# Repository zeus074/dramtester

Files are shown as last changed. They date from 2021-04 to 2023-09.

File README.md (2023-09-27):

# Dramtester V 4.2.1 by Mirco Gaggiottini
Dram tester for 4116 and 4164/256 (now in beta testing for serial communication)

Simple project taken from the base of @FozzTexx

with added support for 4116 memories and a status display.

This Tester supports 4164,41256,4116,*4532* and pin compatible Dram.

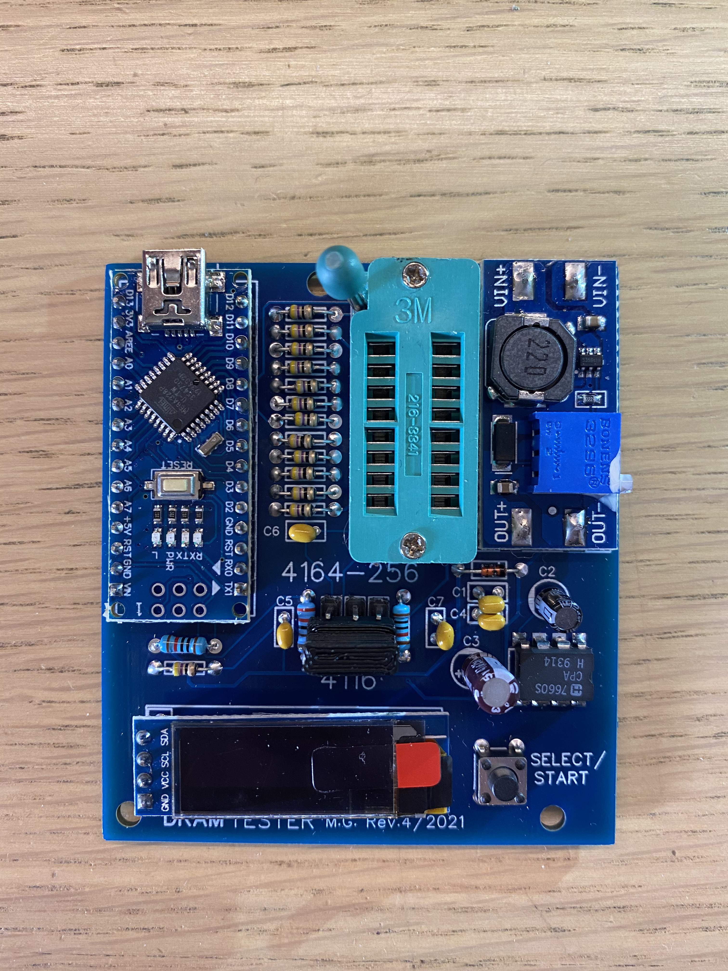
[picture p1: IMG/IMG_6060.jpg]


:coffee: if you want the PCB, please support me and follow this link : <a href="https://www.pcbway.com/project/shareproject/Dram_tester_for_4116_4164_256_and_4532_d6b7143c.html" target="_NEW">PCBWAY!</a>

**Components:**

C1,C4,C5,C6,C7: 100nF

C2: 10uF 25v

C3: 47uf 25v

D1: BAT43 (optional, you can short)

DC: MT3608 (DC-DC converter - 4~5V in, 12V out)

Disp: Display oled 128x32 i2c

H1,H2,H3: 3 pin Header-Male 2.54

R1-R13: 47 Ω 1/8w (optional)

R14,R16: 10k Ω 1/4w

R15: 2.2k Ω 1/4w

1x Arduino Nano

1x Zif 16 pin (or 16 pin socket)

1x 7760 (7660s)

1x tactile switch 6x6

N.B.: The DC-DC must be able to accept 4V on input and must be set to output 12V

**Directory**

Gerber : https://www.pcbway.com/project/shareproject/Dram_tester_for_4116_4164_256_and_4532_d6b7143c.html

IMG : Tester's pictures

Firmware : Firmware for Arduino Nano (you can use avr commands like Arduino's IDE or an AVR programmer to write the HEX file)

Source : Source file to compile for Arduino

Beta folder (inside firmware/source) : software/firmware with serial communication, without LCD (9600 baud)

**How it works**

First you need to flash the firmware on arduino of course!.

Before inserting the ram select the correct setting with the jumpers: (all jumpers must be in the same position, all high for 4164 or all low for 4116)



If the setting is on 4164-256 it is possible to select the type of memory (from 4164,41256,4532-L,4532-H) by briefly pressing the select / start key.
(memory 4116 has no selections)

To start the test, keep the select / start key pressed for 1 sec.

After the test the result will be displayed, if there is an error the test will stop and the point of the error will be shown.

**How to burn the firmware**

You can use avrdude integrated on arduini via command line, or simply download a gui (if you use windows) like AVRDUDESS.
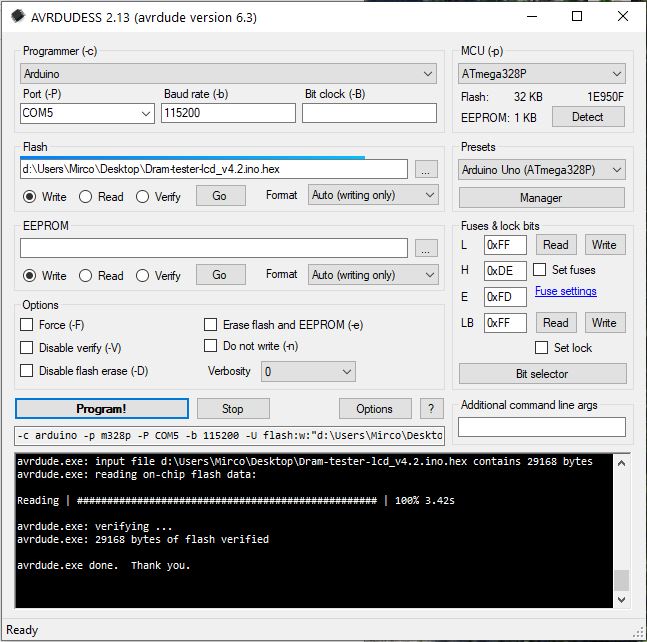
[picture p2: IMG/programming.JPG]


**Support 3D Print**

Thanks to seanch80, you can print the base in 3D, the stl file is in the 3D_print folder.
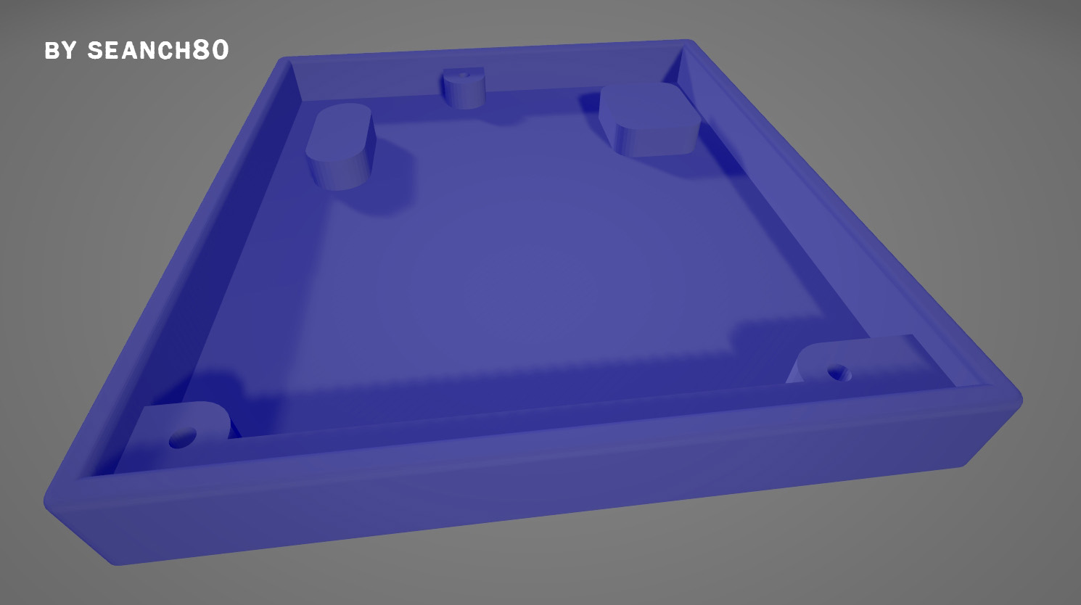
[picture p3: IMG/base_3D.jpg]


You will also find a "3jumpers" file to be able to glue the 3 jumpers in order to easily move them all together.
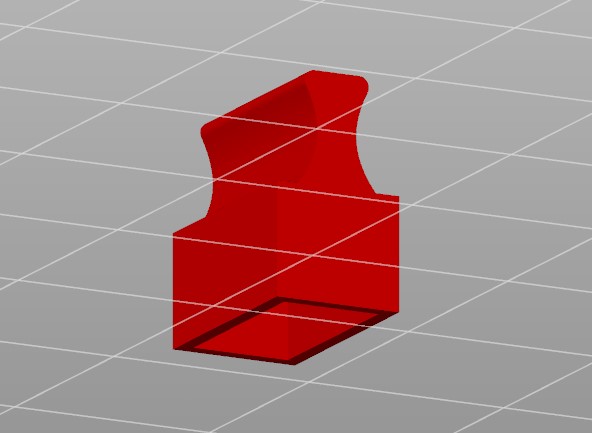
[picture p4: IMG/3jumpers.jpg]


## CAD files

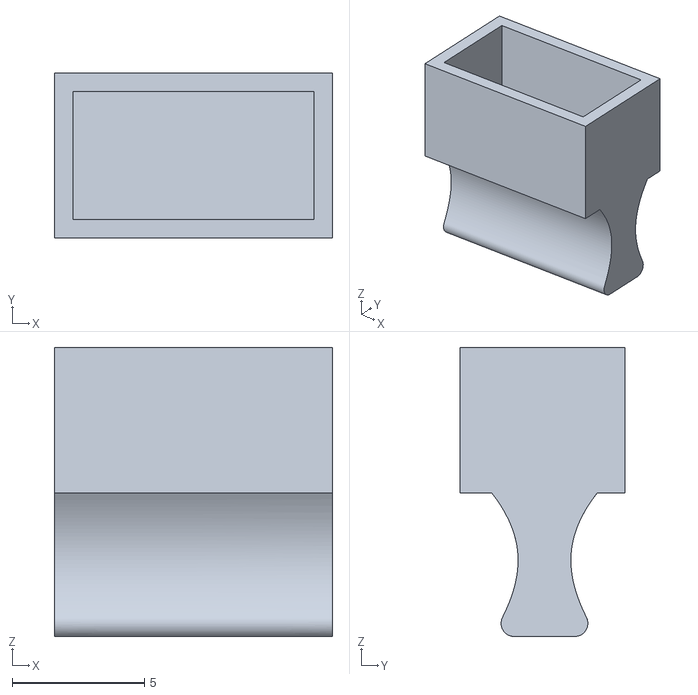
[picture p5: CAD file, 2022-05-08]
3D_Print/3jumpers.stl
10.5 x 6.25 x 10.9

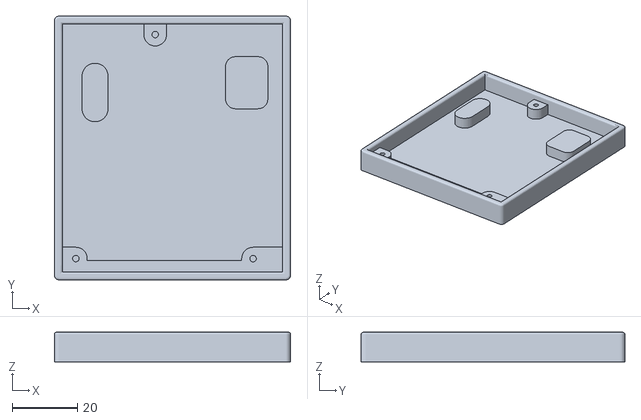
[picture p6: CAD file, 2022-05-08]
3D_Print/DRAMTesterBase_01.stl
72.6 x 81.1 x 9.10

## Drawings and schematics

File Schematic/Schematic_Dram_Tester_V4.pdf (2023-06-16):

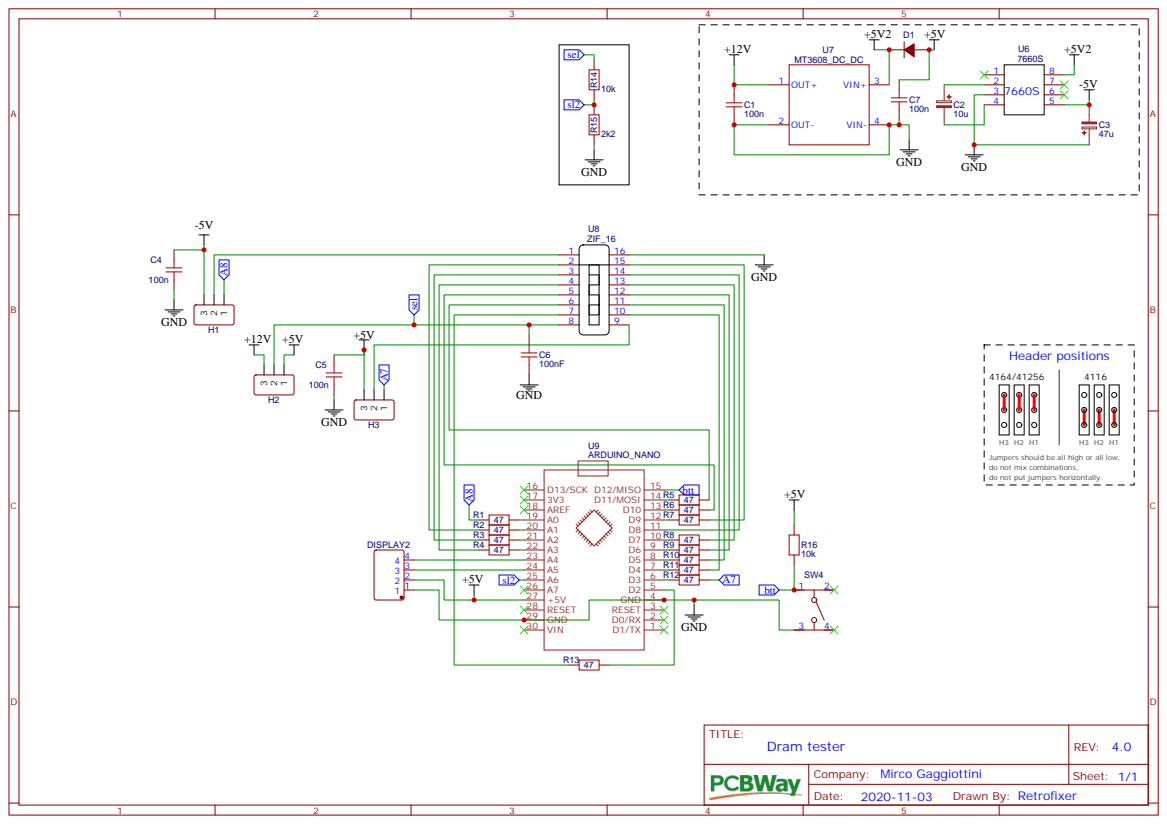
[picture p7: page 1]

Jumpers should be all high or all low,
do not mix combinations,
do not put jumpers horizontally.

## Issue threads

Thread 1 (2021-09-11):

.INO file for Arduino IDE

repetto74, 2021-09-11:
Hi,
I am building this very nice project.
I used to program my Arduino boards with the Arduino IDE but it requires files with .ino extension (while yours is a compiled hex).
Any chance to add also the .ino file to load on the Arduino IDE?
Many thanks.
Rick

zeus074, 2021-09-13:
Hi, yes the .ino file is the source code and is still under development, so I had put the hex and update it from time to time. if you want you can also load the hex with the Arduino compiler, you have to go from the command line to the folder where the software is installed and launch avrdude.
ES:
C: \ Users \ "Your username" \ AppData \ Local \ Arduino15 \ packages \ arduino \ tools \ avrdude \ 6.3.0-arduino17 / bin / avrdude -CC: \ Users \ "your username" \ AppData \ Local \ Arduino15 \ packages \ arduino \ tools \ avrdude \ 6.3.0-arduino17 / etc / avrdude.conf -v -patmega328p -carduino -PCOM5 -b115200 -D -Uflash: w: C: \ Path hex file "win-temp \ arduino_build_678219 / Dram -lcd_v4.2.ino.hex-tester: i

Alternatively you can simply download an ide for avrdude and launch the firmware from there:
https://blog.zakkemble.net/avrdudess-a-gui-for-avrdude/

repetto74, 2021-09-13:
Hi Mirco,

Thank you for your time :-)
I finally tried AVRDUDESS on a Windows machine (I am on MacOSX) and I could
load the hex pretty easily on the Nano :-)
Still waiting for the PCB to build this nice project.
I assume that the DC DC booster converter needs to be set to +12v (with the
variable resistor) as those will be used by the 4116s ?
Best regards,
Riccardo

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

--
Riccardo Repetto
@ AppleWorld...

zeus074, 2021-09-13:
Yes the dc-dc converter must be set to 12v. for dram 4116s i have never tried them but i think it works.
Regards.

Mirco.

repetto74, 2021-09-30:
Ciao Mirco :-)

Ho capito che sei italiano, hai un canale Youtube.
Ho montato il tuo tester DRAM e funziona benissimo con le 4164 :-).
Riscontro pero' un problema per le 4116. Ho cercato di regolare il booster
a +12v in uscita ma niente quando giro il potenziometro il voltaggio non si
muove sul multimetro e rimane a 3.9v in uscita. In entrata ho 4v precisi il
che sembra bassino mentre sull'Arduino mini misuro 4.6v.
Non capisco dove stia sbagliando nel cercare di regolare il booster.
Possibile che sia fallato? Ne ho altri di ricambio ma forse prima dovrei
controllare altro?

PS : I jumper sono stati posizionati correttamente sulle 4116.

Grazie in anticipo per il tuo eventuale consiglio :-)
Riccardo

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

--
Riccardo Repetto
@ AppleWorld...

zeus074, 2021-09-30:
Ciao Ricardo, il booster sarebbe meglio se regolato prima di metterlo nel circuito così sei sicuro del suo funzionamento, ma non è sicuramente questo il problema. La 12V è usata solo nell selettore - pin del 4116, quindi da escludere un abbassamentp da assorbimento anomalo.
Controlla che il booster accetti una tensione di 4-5v in ingresso, alcuni funzionano solo con tensioni più elevate.
Controlla anche i pin di ingresso che magari non fosse stato collegato al contrario se non ci sono serigrafie ad indicare in - out.
Se tutto questo è corretto allora non funziona il dc-dc.
il dc-dc che ho usato io è questo:
https://www.amazon.it/dp/B07MY3NZ18/ref=cm_sw_em_r_mt_dp_EECSXGNEZ534HXSNFZWJ?_encoding=UTF8&psc=1

repetto74, 2021-10-01:
Ciao Mirco,

Ho preso questo booster per 4 lire su Aliexpress pensando fosse una sola
:-). Ma vedi a non sapere bene come usarlo si pensa male.
Devo dare parecchi giri al trimmer per iniziare a vedere un cambiamento dei
valori delle tensioni. Dopo 10 giri mi fermavo pensando che non funzionasse
invece bisogna dare almeno 20 giri e più per regolarlo :-). Adesso funziona
con +12v precisi in uscita sul multimetro :-).
Ottimi progetto mi mancava questo tester RAM quando aggiusto le PCB dei C64
e macchine Spectrum :-)
Grazie a te!
Riccardo

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

--
Riccardo Repetto
@ AppleWorld...

Closed 2021-09-13.

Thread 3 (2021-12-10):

What is the use of the DC-DC converter and what is the expected input-output voltage values?

jsanpe, 2021-12-10:
I came across this tester while looking for a way to test my 4164 ram chips. Looks really neat. However the documentation does not specify how the dc-dc converter is used, and especifically the input-output voltages it expects.

Thanks in advance for your help

zeus074, 2021-12-10:
Hi, the dc-dc just accept 5v input and the output must be adjusted to 12v.
One like this:  https://www.amazon.it/dp/B079H3YD8V/ref=cm_sw_em_r_mt_dp_5123NFZSSCG85CHP4JRM?_encoding=UTF8&psc=1
They are called MT3608

jsanpe, 2021-12-10:
Thanks, maybe worth updating the readme.md to specify the 12v expected output.
Cheers

Closed 2021-12-10.

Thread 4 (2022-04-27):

PCBWay gerbers

electron99, 2022-04-27:
Hello,

Is this PCBWay account yours?

https://www.pcbway.com/project/shareproject/Dram_Tester_OLED_7f572d5b.html

zeus074, 2022-04-27:
Hi, no it's not my account.
Someone have printed it and inserted on Pcbway, I found it also on Ebay

Closed 2022-05-08.

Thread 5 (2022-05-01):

Roughly -4V instead of -5V

seanch80, 2022-05-01:
Hello.  Taking the 5V (more realistically 4.7V if powered via USB) from the Arduino +5V pin and routing it through the diode only gives about ~4V into the 7660S, giving a resulting negative voltage of about -4V. According to the datasheet of a randomly chosen 4116 DRAM chip, the min/max acceptable values for the -5V line is -4.5V to -5.5V.

How does that work? Are typical 4116 DRAM chips not so picky when it comes to the -5V line?

Also, I wonder why the 1N4148 diode was chosen, and not a schottky diode or other with less voltage drop?

zeus074, 2022-05-02:
Yes, you are right, the voltage could be a bit at the limit. I have seen from the tests that it works ,but to improve it without modifying the scheme, just replace the 1n4148 diode with a Schottky one such as BAT43 or similar.
It is also possible to remove the diode and put a jumper, this was left over from the old version where I supplied the 12V externally.

seanch80, 2022-05-02:
Thanks for the explanation. I think I will use a jumper instead of the diode then.

seanch80, 2022-05-08:
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

..with the diode replaced by a jumper. 😄

seanch80, 2022-05-08:
[DRAMTesterBase_01.zip](https://github.com/zeus074/dramtester/files/8646154/DRAMTesterBase_01.zip)

STL file of 3D printed base.

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

zeus074, 2022-05-08:
good job!
I post the file on Github with thanks.
I also added the stl for print the handle to glue all the jumpers and move them more easily between the high and low position.
👍

seanch80, 2022-05-09:
Very nice. Thanks for sharing this project on github. It was fun to build and works great!

Closed 2022-05-02.

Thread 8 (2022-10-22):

No 12V output, only about 5V through the MT3608

feltel, 2022-10-22:
I just built a DRAM tester with your PCB. Thanks for sharing. I came across an issue with the 12V DC-converter. If I connect the tester the proper way through the Arduino I get only about 5V out of the MT3608 converter. So I cannot use it to test 4116 RAM. If I feed the tester via a bench power supply (set to 5V/1A) and connect it to the VIN terminals I get the desired voltage of 12V at the VOUT terminals. I don get it. There is not much between the Arduino power output pin and the VIN terminal. I double and tripple checked the resistor values and everything else. I used an resistor lead instead of the diode at D1 as discussed in another issue here. Am I missing something?

zeus074, 2022-10-22:
Hi, the 5V is taken from Arduino pin 27 and powers the 7660 display and the step-up as well as the ram.
The diode was giving problems to the 7660 because it could lower the voltage too much.
You can try to check the input voltages at the step-up or put a temporary wire up to pin 27 of the Arduino.
Alternatively, try to use the diode to power only the step-up, to eliminate any return disturbances.
Otherwise I think the problem may be Arduino or the step-up.

feltel, 2022-10-24:
Dear Mirco,
I replaced the wire at D1 with an diode as per the BOM. The voltage at the 12V rail dropped as expected even more. Its now at around 3,9V. The arduino outputs about 5V at Pin 17. As next test I soldered an patch wire from the Arduino socket, Pin 17 to the VIN+ MT3608 at the underside of the board. No change in voltage. I moved the patch wire to the top side of the MT3608 (just to rule out a non optimal connection), but no change at all. I switched the arduino to another one, but also no change. I have flashed two arduinos, one from AliExpress (due to USB-C connector) and one from an "trusted" local source. But both arduinos show the same behaviour. I'm out of ideas and cannot explain, why I get the expected voltage if I use an bench power supply connected to VIN+, but not with the arduino.

giobbino, 2022-11-26:
feltel, I my case it works fine. I set the DC-DC converter at 12v before to solder it on the board, and now it's supplying 12v when powered by Arduino.

I should add that I'm not using an Arduino Nano; instead, I'm using a drop-in replacement, the Mini-EVB LGT8F328P-LQFP32 a 32bit board that runs at 32MHz... but it shouldn't make any difference about that.

I bought the DC-DC converter on Aliexpress (not the most reliable source, indeed) but it works fine. Are you sure you haven't some issue with your DC-DC converter?

feltel, 2022-12-02:
I'm not sure regarding the converters. But why does it work when "jump starting" directly from the converter. I have some converters from another source on back order and will give it a try asap.

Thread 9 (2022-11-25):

Jumpers have no effect (doesn't change between 4116 and 4165/256)

giobbino, 2022-11-25:
This is quite a trivial issue, but since it took a little to understand what was wrong, I just want to leave a clue (also because some note inside the code are in italian... perfect for me, but not so good for somebody LOL).

Issue: no effect moving the three jumpers on High or Low.

Looking at the source code, in the function.ino -> selchip() there's a static declaration about the three values: off, 4116 and 4164 from the A6 pin: below 10 is OFF, between 10 and 200 is 4164, otherwise is 4116.

In my configuration, the setting for 4164 returns about 720-730 and for 4116 is above 1800.

So if you experienced the same problem, you should open the source code, find the selchip() function  and activate the line:

   Serial.println(MREAD);

Then compile, upload and run the code on your RAM tester, and open the serial monitor with Ctrl+Shift+M ( ** CHECK THE SPEED IS 9600!)

Check the three jumpers setup: no jumper, 4164 and 4116.

Then come back in the selchip() function and fix the lines with the correct values:

if (MREAD<10) {//4164     <<< put a value a little above the "no jumper" config. if it is zero, this line is already ok
      return 0;
} else if (MREAD<200) {//4164-256-32   <<put a value a little above the "2164 jumper" config. in my case was ~730 so I put 800

This should fix the issue.

------------------------
I have to say I used a "nano-clone", drop-in replacement board, the Mini-EVB LGT8F328P-LQFP32 @ 32MHz. This board should be an almost perfect clone of an Arduino Nano, but I can't 100% guarantee about that.

Cheers,
Giovi

zeus074, 2022-11-26:
this may depend on the supply voltage and resistance values, I calibrated them according to the settings I had. to avoid problems, the intervention range can be increased. check with mine and in case I increase the value.
I got these values: (when I write the code)
0=key on 4164 510=empty key 1024=key on 4116

1800 seems like a very high value to me.

giobbino, 2022-11-26:
I think you mean 0=empty and 510=key on 4164 (your comments in the code seems to be different from the source code)

I got: 0=empty; 720~730=4164; 1815~1817=4116.

I could depend by the different board (Mini-EVB LGT8F328P-LQFP32) I used, but I'm not really sure about it, since I used that board in many projects (it was 1/2 the price of an Arduino Nano clone so I bought some of them) and I never experienced any issue. However, no problem at all, just a matter of setting the value in the source code.

To make the things simpler, I slightly modify your code:

I added two lines at the top of the main sketch...
#define RAM_NDEF  10    // <   10 = empty
#define RAM_4164  1000  // < 1000 = 4164

...and I modify the selchip() function accordingly
    if (MREAD<RAM_NDEF) {  //no jumpers
      return 0;
    } else if (MREAD<RAM_4164) { //jumpers on 4164
      return 1;
    } else {  //jumpers on 4116
      return 2;

giobbino, 2022-12-02:
Thank you. Soon or later i will build another with an Arduino Nano, just to see if the problem is the Arduino Nano vs clone or the resistors. However, generally speaking, I see no needs to change the hardware when you can solve changing the software LOL...
With the new values it's working, and it's enough for me.

I also slightly modify you software, adding a FAST / SLOW mode on all modes. The SLOW mode makes more test per bit, writing 0 and 1 alternately. However I didn't see any difference on the RAM chips that were supposed to be bad , so I don't know if there's any good doing that.

Next step, is to test those "bad" (bad?) RAM ICs again in a C=64 and see if they are really bad or not.

giobbino, 2022-12-03:
I've built a second RAM tester, this time using a chinese Arduino Nano. All the others components remain the same, from the same seller and lot.

The values changed dramatically: now I have a value around 185 for the 64/256 setting, and around 473 for the 4116 setup.

Weird, isn't it?

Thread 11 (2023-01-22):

Can't flash firmware

jzmacdaddy, 2023-01-22:
Using AVRDUDESS on multiple machines and using a "real" Arduino Nano I get this error every time trying to flash v4.2.

avrdude.exe: verification error, first mismatch at byte 0x7800
             0xff != 0x2e
avrdude.exe: verification error; content mismatch

I'm not an expert at this stuff, so I don't know if I'm doing something wrong or not.

jzmacdaddy, 2023-01-22:
Download was not "raw", hence the mismatch in uploading to the Nano.

Closed 2023-01-22.

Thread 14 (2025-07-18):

TC7660SEPA alternatives?

theclue, 2025-07-18:
Ciao Mirko! Come stai? :)

I'm going to start building the tester and I sourced all the components but the TC7660SEPA regulator.

Actually, Mouser doesn't offer cheap shipping solutions which is to me quite a waste of money for just this nifty 1 buck component.

Is it possible in your opinion to use a different/equivalent DIP component which is more widely available?

Tnx allot for this nice project! I cannot stay in my shoes to start building!

Saluti!

zeus074, 2025-07-19:
Hi, well thanks.
Unfortunately, to replace that component you need to modify the circuit a bit.
That chip is used to generate the -5V, you can do it in other ways, a fairly simple one is to use an isolated voltage regulator and connect the outputs in reverse, the +5 to gnd and the gnd to -5v.
Without 660S you can omit C2,C3
You can use this component: B0505S/D-1W
https://www.amazon.it/gp/product/B07MR1XV63

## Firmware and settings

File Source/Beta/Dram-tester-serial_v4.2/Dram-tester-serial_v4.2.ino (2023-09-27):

#include <Arduino.h>
#include <U8g2lib.h>
#include <SPI.h>
#include <Wire.h>
#include <EEPROM.h>

//* uncomment this line if you use Display OLED 1306-SSD I2C
// like this : https://www.amazon.it/dp/B0CDLS8F2Y
//if commented, you can use serial monitor @9600 to comunicate with Dram Tester

//#define SSDLCD

#ifdef SSDLCD
U8G2_SSD1306_128X32_UNIVISION_F_HW_I2C u8g2(U8G2_R0); 
#endif

#define DI          15  // PC1
#define DO           8  // PB0
#define CAS          9  // PB1
#define RAS         17  // PC3
#define WE          16  // PC2

#define XA0         10//18  // PC4
#define XA1          2  // PD2
#define XA2         11//19  // PC5
#define XA3          6  // PD6
#define XA4          5  // PD5
#define XA5          4  // PD4
#define XA6          7  // PD7
#define XA7          3  // PD3
#define XA8         14  // PC0

#define M_START     12  // Start/mode 
//#define M_CHIPSEL   12 // Selector 4116 / 4164
#define M_CHIPSEL   A6 // Selector 4116 / 4164
#define BUS_SIZE     9
/*
 * GENERAL PINOUT ARDUINO
 * D1 = SWITCH START TEST
 * A4 = LCD
 * A5 = LCD
 * D12 = SWITCH MODE (5V) 4116 - (GND) 4164/256
 *
 *menù
 *sw 4116                             -                         4164/256
 *press start (2 sec to start test)   - press stat to select 4164/256, 4532L 4532H, long press to start test
 *
 */


int mode;
int lastState = HIGH;
int currentState;
unsigned long pressedTime = 0;
byte selector = 0;
byte l_sel = 0;
bool isError = false;
byte ntest =0;

String  m_sym[2] = {"\\","/"};

volatile int bus_size;
const unsigned int a_bus[BUS_SIZE] = {
  XA0, XA1, XA2, XA3, XA4, XA5, XA6, XA7, XA8
};


/* -----  SETUP  ------ */
 void setup() {
  int i;
  #ifdef SSDLCD
   u8g2.begin();
  #else
  Serial.begin(9600); 
  #endif

   

for (i = 0; i < BUS_SIZE; i++)
    pinMode(a_bus[i], OUTPUT);

  pinMode(CAS, OUTPUT);
  pinMode(RAS, OUTPUT);
  pinMode(WE, OUTPUT);
  pinMode(DI, OUTPUT);
  //pinMode(M_CHIPSEL, INPUT);
  pinMode(M_START, INPUT);
  pinMode(DO, INPUT);
  digitalWrite(WE, HIGH);
  digitalWrite(RAS, HIGH);
  digitalWrite(CAS, HIGH);

  mode =EEPROM.read(0);//memoria 4164-256-32l-32h
  if (mode>3){mode=0;}

/*
if (digitalRead(M_TYPE)) {
    /* jumper not set - 41256 */
    /*bus_size = BUS_SIZE;
    //Serial.print("256Kx1 ");
  } else {
    /* jumper set - 4164 */
    /*bus_size = BUS_SIZE - 1;
    //Serial.print("64Kx1 ");
  }*/
  
  #ifdef SSDLCD
  //luk74();
  delay(5000);
  #else
  Serial.println("DRAMTESTER 4.2 BY RETROFIXER");
  Serial.println("");
  #endif
  selector=selchip();
  l_sel=selector;
  setDisp();
}
/* -----------  LOOP  ---------- */
  void loop(void) {

    //getserial();

    selector=selchip(); // 0= vuoto 1=4164 2=4116

    if (l_sel!=selector) {
      l_sel=selector;
      setDisp();
    }
      
   //change mode - start
   currentState = digitalRead(M_START);
  if (lastState == HIGH && currentState == LOW) { // button is pressed
    pressedTime = millis();
    lastState = LOW;
  }
  if(lastState == LOW && currentState == HIGH) { // button is released
    lastState = HIGH;
    long pressDuration = millis() - pressedTime;
    if (pressDuration < 1500 ) { //short press chenge mode
      if (selector==1 ){
        mode++;
        if (mode > 3) mode=0;
        EEPROM.write(0, mode);
        setDisp();
      }
    }
  }
    if(lastState == LOW && currentState == LOW &&  millis() - pressedTime > 1500) {
    //else { //long press start
      isError=false;
      ntest=0;
      if (selector>0) startTest();
  }
   
   delay(100);
}

   
void startTest() {
   initDram();
   #ifdef SSDLCD
   u8g2.clearBuffer();
   u8g2.setFont(u8g2_font_logisoso16_tr);
   u8g2.drawStr(8,16,"Test no.1");
   u8g2.setFont(u8g2_font_gb16st_t_2);
   #else
   Serial.println("> Start Test..");
   Serial.println("Test no.1");
   #endif
   switch (selector) {
    case 2:
    #ifdef SSDLCD
    u8g2.drawStr(4,32,">16k");
    #else
    Serial.println("(16k)");
    #endif
    bus_size = BUS_SIZE - 2;
    break;
    case 1:
      if (mode == 0){
      #ifdef SSDLCD
      u8g2.drawStr(4,32,">256k");
      #else
      Serial.print("(256k)");
      #endif
      bus_size = BUS_SIZE;
      } else {
      bus_size = BUS_SIZE - 1;
      }
      #ifdef SSDLCD
      if (mode == 1) u8g2.drawStr(4,32,">64k");
      if (mode == 2) u8g2.drawStr(4,32,">32k Low");
      if (mode == 3) u8g2.drawStr(4,32,">32k High");
      #else
      if (mode == 1) Serial.print("(64k)");
      if (mode == 2) Serial.print("(32k Low)");
      if (mode == 3) Serial.print("(32k High)");
      #endif
   }

  #ifdef SSDLCD
  u8g2.sendBuffer();
  #endif
  interrupts(); noInterrupts(); 
  
  fillx(0);
  if (!isError){
    resDisp("Test no.2");
    interrupts();
    #ifdef SSDLCD
    u8g2.sendBuffer();
    #endif
    noInterrupts(); 
    fillx(1);
  }
  if (!isError){
    interrupts(); 
    resDisp("Full Write...");
    #ifdef SSDLCD
    u8g2.sendBuffer();
    #endif
    noInterrupts(); 
    fill(1,false);
  }
  if (!isError){
    interrupts(); 
    resDisp("Full Read...");
    #ifdef SSDLCD
    u8g2.sendBuffer();
    #endif
    noInterrupts(); 
    readonly(1);
  }
    if (!isError){
   resDisp("Finishing...");
    interrupts();
    #ifdef SSDLCD
    u8g2.sendBuffer();
    #endif
    noInterrupts(); 
    fill(0,true);
  }

  interrupts();
  
  if (!isError){
   finish();
   /*
   u8g2.clearBuffer();
   u8g2.setFont(u8g2_font_logisoso16_tr);
   u8g2.drawStr(6,16,"TEST PASSED");
   u8g2.setFont(u8g2_font_gb16st_t_2);
   u8g2.drawStr(12,30,"press start");
   u8g2.sendBuffer();*/
         while (digitalRead(M_START)==LOW) {
      }
          while (digitalRead(M_START)==HIGH) {
      }
      setDisp();
      delay(300);
  } else {
    setDisp();
  }
}

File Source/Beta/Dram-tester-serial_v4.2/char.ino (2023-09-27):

// '1', 128x64px
const unsigned char frame1 [] PROGMEM = {
  0x00, 0x00, 0x00, 0x00, 0x00, 0x00, 0x00, 0x00, 0x00, 0x00, 0x00, 0x00, 
  0x00, 0x00, 0x00, 0x00, 0x00, 0x00, 0x00, 0x00, 0x00, 0x00, 0x00, 0x00, 
  0x00, 0x00, 0x00, 0x00, 0x00, 0x00, 0x00, 0x00, 0x00, 0x00, 0x00, 0x00, 
  0x00, 0x00, 0x00, 0x00, 0x00, 0x00, 0x00, 0x00, 0x00, 0x00, 0x00, 0x00, 
  0x00, 0x00, 0x00, 0x00, 0x00, 0x00, 0x00, 0x00, 0x00, 0x00, 0x00, 0x00, 
  0x00, 0x00, 0x00, 0x00, 0x00, 0x00, 0x00, 0x00, 0x80, 0x00, 0x00, 0x00, 
  0x00, 0x00, 0x00, 0x00, 0x00, 0x00, 0x00, 0x00, 0x00, 0x00, 0x00, 0x00, 
  0x80, 0x33, 0x00, 0x00, 0x00, 0x00, 0x00, 0x00, 0x00, 0x00, 0x00, 0x00, 
  0x00, 0x00, 0x00, 0x00, 0xF0, 0x7F, 0x00, 0x00, 0x00, 0x00, 0x00, 0x00, 
  0x00, 0x00, 0x00, 0x00, 0x00, 0x00, 0x00, 0x00, 0xF8, 0xFF, 0x04, 0x00, 
  0x00, 0x00, 0x00, 0x00, 0x00, 0x00, 0x00, 0x00, 0x00, 0x00, 0x00, 0x00, 
  0x80, 0xFF, 0x07, 0x00, 0x10, 0x12, 0x06, 0x00, 0x00, 0x00, 0x00, 0x00, 
  0x00, 0x20, 0x00, 0x00, 0x06, 0xFC, 0x0F, 0x00, 0xFC, 0xC3, 0x01, 0x00, 
  0x00, 0x00, 0x00, 0x00, 0x00, 0x60, 0x00, 0xC0, 0x3B, 0xE0, 0x3F, 0x00, 
  0x49, 0x1E, 0x48, 0x00, 0x00, 0x00, 0x00, 0x00, 0x00, 0xE0, 0x07, 0xF0, 
  0xF9, 0x83, 0x3F, 0x00, 0xC9, 0xF9, 0x00, 0x01, 0x00, 0x00, 0x00, 0x00, 
  0x00, 0xE0, 0xFF, 0xFF, 0xFD, 0x1D, 0x1E, 0x80, 0xF9, 0xB7, 0x5F, 0x08, 
  0x00, 0x00, 0x00, 0x00, 0x00, 0xC0, 0xFF, 0x7F, 0xFC, 0x7C, 0x18, 0x80, 
  0xD1, 0x7F, 0x06, 0x02, 0x00, 0x00, 0x00, 0x00, 0x00, 0xE0, 0xFF, 0x1F, 
  0xF8, 0xFE, 0x31, 0xE0, 0xD9, 0xFC, 0x43, 0x20, 0x00, 0x00, 0x00, 0x00, 
  0x00, 0x40, 0xFF, 0xE1, 0x63, 0xBE, 0x07, 0xE0, 0x91, 0xFD, 0x1F, 0x04, 
  0x00, 0x00, 0x00, 0x00, 0x00, 0x00, 0x54, 0xFC, 0x6F, 0x3F, 0xF7, 0xF5, 
  0xED, 0xDE, 0xDF, 0x00, 0x00, 0x00, 0x00, 0x00, 0x00, 0x00, 0x00, 0x7E, 
  0x00, 0xFF, 0xFB, 0xFF, 0xCD, 0xE3, 0x6F, 0x50, 0x00, 0x00, 0x00, 0x00, 
  0x00, 0x00, 0x00, 0xBE, 0x7F, 0xFE, 0xF9, 0xFF, 0x79, 0xFF, 0x3F, 0x01, 
  0x04, 0x00, 0x00, 0x00, 0x00, 0x00, 0x00, 0xDF, 0xFF, 0xF0, 0xFB, 0xFF, 
  0xB9, 0xFF, 0xFF, 0x1F, 0x10, 0x00, 0x00, 0x00, 0x00, 0x00, 0x80, 0xDF, 
  0xFF, 0x07, 0xC0, 0xFF, 0xCC, 0xFE, 0xF9, 0xFF, 0xFF, 0xFF, 0xFF, 0xFF, 
  0x00, 0x00, 0xC0, 0xDF, 0xFF, 0xFF, 0x1F, 0x00, 0x8C, 0xD3, 0xFF, 0xFF, 
  0xFF, 0xFF, 0xFF, 0xFF, 0x00, 0x00, 0xE0, 0xEF, 0xFF, 0xFF, 0xFF, 0xFF, 
  0xE8, 0xE9, 0xFF, 0xFF, 0xFF, 0xFF, 0xFF, 0xFF, 0x00, 0x00, 0xF0, 0xEF, 
  0xFF, 0xFF, 0xFF, 0xFF, 0xC9, 0xFF, 0xFF, 0x03, 0x80, 0x00, 0x00, 0x00, 
  0x00, 0x00, 0xF0, 0xEF, 0xFF, 0xFF, 0xFF, 0xFF, 0xE9, 0x5B, 0xDF, 0x00, 
  0x22, 0x00, 0x00, 0x00, 0x00, 0x00, 0xF8, 0xDF, 0xFF, 0xFF, 0xFF, 0xFF, 
  0xE9, 0xDF, 0x37, 0x22, 0x00, 0x00, 0x00, 0x00, 0x00, 0x00, 0xF8, 0xDF, 
  0xFF, 0xFF, 0xFF, 0xFF, 0xE9, 0xAE, 0x7F, 0x00, 0x00, 0x00, 0x00, 0x00, 
  0x00, 0x00, 0xF8, 0x3F, 0xFF, 0xFF, 0xFF, 0xFF, 0xE9, 0xE6, 0x00, 0x12, 
  0x00, 0x00, 0x00, 0x00, 0x00, 0x00, 0xF8, 0xFF, 0x00, 0x40, 0xFA, 0xFF, 
  0xB9, 0x73, 0x93, 0x00, 0x00, 0x00, 0x00, 0x00, 0x00, 0x00, 0xF8, 0xFF, 
  0xFF, 0x0F, 0x00, 0xE0, 0xF9, 0xBB, 0x05, 0x00, 0x00, 0x00, 0x00, 0x00, 
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
};
// '2', 128x64px
const unsigned char frame2 [] PROGMEM = {
  0x00, 0x00, 0x00, 0x00, 0x00, 0x00, 0x00, 0x00, 0x00, 0x00, 0x00, 0x00, 
  0x00, 0x00, 0x00, 0x00, 0x00, 0x00, 0x00, 0x00, 0x00, 0x00, 0x00, 0x00, 
  0x00, 0x00, 0x00, 0x00, 0x00, 0x00, 0x00, 0x00, 0x00, 0x00, 0x00, 0x00, 
  0x00, 0x00, 0x00, 0x00, 0x00, 0x00, 0x00, 0x00, 0x00, 0x00, 0x00, 0x00, 
  0x00, 0x00, 0x00, 0x00, 0x00, 0x00, 0x00, 0x00, 0x00, 0x00, 0x00, 0x00, 
  0x00, 0x00, 0x00, 0x00, 0x00, 0x00, 0x00, 0x20, 0x00, 0x00, 0x00, 0x00, 
  0x00, 0x00, 0x00, 0x00, 0x00, 0x00, 0x00, 0x00, 0x00, 0x00, 0x00, 0xE0, 
  0x0C, 0x00, 0x00, 0x00, 0x00, 0x00, 0x00, 0x00, 0x00, 0x00, 0x00, 0x00, 
  0x00, 0x00, 0x00, 0xFC, 0x1F, 0x00, 0x00, 0x00, 0x00, 0x00, 0x00, 0x00, 
  0x00, 0x00, 0x00, 0x00, 0x00, 0x00, 0x00, 0xFE, 0x3F, 0x01, 0x00, 0x00, 
  0x00, 0x00, 0x00, 0x00, 0x00, 0x00, 0x00, 0x00, 0x00, 0x00, 0x00, 0xE0, 
  0xFF, 0x01, 0x00, 0x84, 0x84, 0x01, 0x00, 0x00, 0x00, 0x00, 0x00, 0x00, 
  0x08, 0x00, 0x80, 0x01, 0xFF, 0x03, 0x00, 0xFF, 0x70, 0x00, 0x00, 0x00, 
  0x00, 0x00, 0x00, 0x00, 0x08, 0x00, 0xF0, 0x0E, 0xF8, 0x0F, 0x40, 0x92, 
  0x07, 0x12, 0x00, 0x00, 0x00, 0x00, 0x00, 0x00, 0xF8, 0x01, 0x7C, 0xFE, 
  0xE0, 0x0F, 0x40, 0x72, 0x3E, 0x40, 0x00, 0x00, 0x00, 0x00, 0x00, 0x00, 
  0xF8, 0xFF, 0x7F, 0x7F, 0x87, 0x07, 0x60, 0xFE, 0xED, 0x17, 0x02, 0x00, 
  0x00, 0x00, 0x00, 0x00, 0xF0, 0xFF, 0x1F, 0x3F, 0x1F, 0x06, 0x60, 0xF4, 
  0x9F, 0x81, 0x00, 0x00, 0x00, 0x00, 0x00, 0x00, 0xF8, 0xFF, 0x07, 0xBE, 
  0x7F, 0x04, 0x78, 0x36, 0xFF, 0x10, 0x08, 0x00, 0x00, 0x00, 0x00, 0x00, 
  0xD0, 0x7F, 0xF8, 0x98, 0xEF, 0x05, 0x78, 0x64, 0xFF, 0x07, 0x01, 0x00, 
  0x00, 0x00, 0x00, 0x00, 0x00, 0x1A, 0xFF, 0xDB, 0xCF, 0xBF, 0x7D, 0xBB, 
  0xF7, 0x37, 0x00, 0x00, 0x00, 0x00, 0x00, 0x00, 0x00, 0x80, 0x1F, 0xC0, 
  0xFF, 0xFE, 0x7F, 0xF3, 0xF8, 0x1B, 0x14, 0x00, 0x00, 0x00, 0x00, 0x00, 
  0x00, 0x80, 0xEF, 0x9F, 0x7F, 0xFE, 0x7F, 0xDE, 0xFF, 0x4F, 0x00, 0x01, 
  0x00, 0x00, 0x00, 0x00, 0x00, 0xC0, 0xF7, 0x3F, 0xFC, 0xFE, 0x7F, 0xEE, 
  0xFF, 0xFF, 0x07, 0x04, 0x00, 0x00, 0x00, 0x00, 0x00, 0xE0, 0xF7, 0xFF, 
  0x01, 0xF0, 0x3F, 0xB3, 0x7F, 0xFE, 0xFF, 0xFF, 0xFF, 0xFF, 0xFF, 0xFF, 
  0x00, 0xF0, 0xF7, 0xFF, 0xFF, 0x07, 0x00, 0xE3, 0xF4, 0xFF, 0xFF, 0xFF, 
  0xFF, 0xFF, 0xFF, 0xFF, 0x00, 0xF8, 0xFB, 0xFF, 0xFF, 0xFF, 0x3F, 0x7A, 
  0xFA, 0xFF, 0xFF, 0xFF, 0xFF, 0xFF, 0xFF, 0xFF, 0x00, 0xFC, 0xFB, 0xFF, 
  0xFF, 0xFF, 0x7F, 0xF2, 0xFF, 0xFF, 0x00, 0x20, 0x00, 0x00, 0x00, 0x00, 
  0x00, 0xFC, 0xFB, 0xFF, 0xFF, 0xFF, 0x7F, 0xFA, 0xD6, 0x37, 0x80, 0x08, 
  0x00, 0x00, 0x00, 0x00, 0x00, 0xFE, 0xF7, 0xFF, 0xFF, 0xFF, 0x7F, 0xFA, 
  0xF7, 0x8D, 0x08, 0x00, 0x00, 0x00, 0x00, 0x00, 0x00, 0xFE, 0xF7, 0xFF, 
  0xFF, 0xFF, 0x7F, 0xBA, 0xEB, 0x1F, 0x00, 0x00, 0x00, 0x00, 0x00, 0x00, 
  0x00, 0xFE, 0xCF, 0xFF, 0xFF, 0xFF, 0x7F, 0xBA, 0x39, 0x80, 0x04, 0x00, 
  0x00, 0x00, 0x00, 0x00, 0x00, 0xFE, 0x3F, 0x00, 0x80, 0xFE, 0x7F, 0xEE, 
  0xDC, 0x24, 0x00, 0x00, 0x00, 0x00, 0x00, 0x00, 0x00, 0xFE, 0xFF, 0xFF, 
  0x03, 0x00, 0x78, 0xFE, 0x6E, 0x01, 0x00, 0x00, 0x00, 0x00, 0x00, 0x00, 
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
};
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

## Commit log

2022-05-08 add stl file for base and jumpers
    [3jumpers.stl, DRAMTesterBase_01.stl]
2022-12-05 Delete Gerber_PCB_Dram-tester_V4.zip
    Removed because it is being resold without permission
2023-06-16 Create Schematic_Dram_Tester_V4.pdf
    schematic added
